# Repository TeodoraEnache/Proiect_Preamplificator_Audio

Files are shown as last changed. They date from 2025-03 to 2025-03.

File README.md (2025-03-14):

# 🔊Audio Preamplifier with Voltage-Controlled Gain – Design and Implementation

## Academic Context
### National University of Science and Technology POLITEHNICA Bucharest  
#### Faculty of Electronics, Telecommunications, and Information Technology  
##### Academic Year 2024-2025 
**Supervisors:**  
- Prof. Dr. Eng. Dragoș Dobrescu  
- Lecturer Dr. Eng. Mădălin Moise  

##  Table of Contents  

1. [ Description](#-description)  
2. [ Download Project](#download-project)  
3. [ Project Overview](#project-overview)  
4. [ Circuit Simulation and Testing](#-circuit-simulation-and-testing)  
   - [ Schematic](#schematic)  
   - [ SPICE Simulation](#spice-simulation)  
     - [First Simulation - Control voltage = 4V](#first-simulation---control-voltage4v)  
     - [Second Simulation - Control voltage = 0V](#second-simulation---control-voltage0v)  
5. [PCB Design](#pcb-design)  
   - [ PCB Layout](#pcb-layout)  
6. [Audio Preamplifier - PCB Layers](#audio-preamplifier---pcb-layers)  
   - [🔷 TOP Layer](#-top-layer)  
   - [🔷 BOTTOM Layer](#-bottom-layer)  
   - [🔷 SMTOP Layer (Solder Mask Top)](#-smtop-layer-solder-mask-top)  
   - [🔷 SMBOT Layer (Solder Mask Bottom)](#-smbot-layer-solder-mask-bottom)  
   - [🔷 SSTOP Layer (Silkscreen Top)](#-sstop-layer-silkscreen-top)  
   - [🔷 Outline Layer (Board Outline)](#-outline-layer-board-outline)  
   - [🔷 Fabrication Layer](#-fabrication-layer) 
7. [Repository Contents](#repository-contents)
8. [Conclusion](#conclusion)
9. [References](#references)

## Project Description: 

 A comprehensive project focused on designing and implementing an audio preamplifier with voltage-controlled gain, adjustable between 1x and 40x. The project includes:  
 • Designing the electrical schematic and simulating functionality using Cadence/Orcad PSpice.  
 • Creating a production-optimized SMD-based PCB layout.  
 • Providing detailed documentation, including theoretical analysis, applications, and manufacturing guidelines.

## Download Project:
[Click here to download the Project as PDF](https://github.com/TeodoraEnache/Proiect_Preamplificator_Audio/blob/main/Enache_Teodora_Preamplificator%20Audio.pdf)

## Project Overview

 The preamplifier is a crucial component of audio signal processing, enhancing low-level signals from sources such as microphones or pickups to levels that are suitable for further processing or amplification.The design's key feature is its voltage-controlled gain, which allows for precise adjustments to the amplification factor.  
 Adaptability is essential for ensuring audio fidelity in different input signal levels.

 ## Circuit Simulation and Testing

 ### Schematic
 
 The circuit schematic consists of a Darlington amplifier stage, which provides high current gain and high input impedance, making it suitable for low-power signal amplification. The circuit operates with a single positive power supply, using a common ground reference. After amplification and filtering, the processed audio signal is directed to the output stage, ensuring high-quality signal transmission.
 <br/>
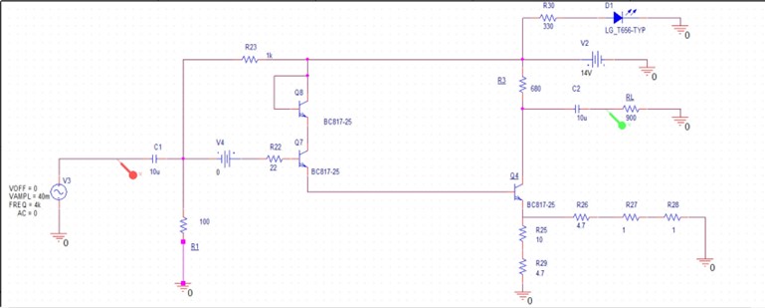
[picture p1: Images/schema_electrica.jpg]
Circuit

 <br/>  

 ### SPICE simulation 

 The result of the SPICE simulation demonstrate how the gain varies with the control voltage.

 #### First Simulation - Control voltage=4V
 The gain is low, when the control voltage is 4V. The output signal(GREEN) is weak, having almost the same amplitude as the imput signal (RED), indicating that the circuit functions as a signal repeater.
 <br/>
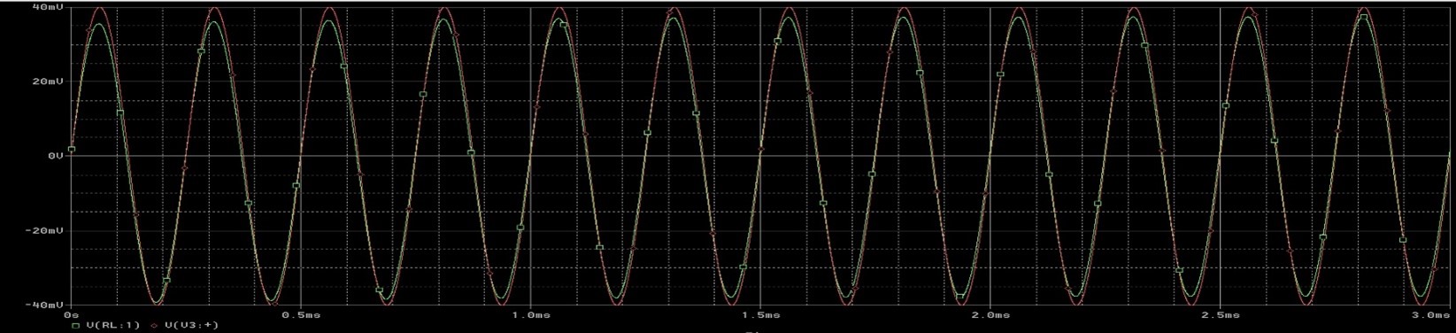
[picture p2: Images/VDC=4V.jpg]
Sim1

<br/>

#### Second Simulation - Control voltage=0V
The gain increases, when the control voltage is 0V. The output signal(GREEN) is amplified significantly, with the output amplitude increased by a factor of 40.
<br/>
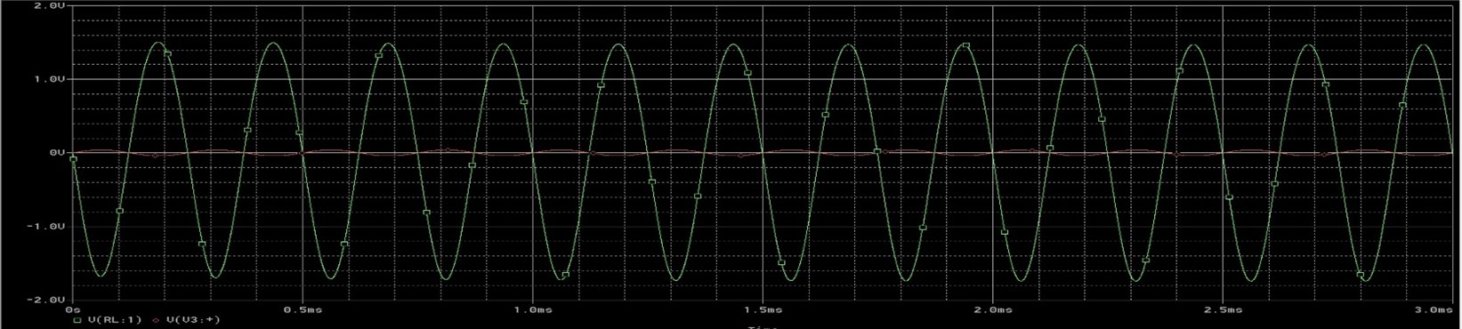
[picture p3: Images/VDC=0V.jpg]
Sim2

<br/>

 ### PCB DESIGN
 A custom PCB was designed for the practical implementation of this circuit. The layout optimizes component placement and signal routing to reduce noise and interference, ensuring a clean, amplified output. Measuring 40mm × 40mm, the compact PCB includes dedicated pads for input, output, power connections, and the control voltage signal, making it easily integrable into various audio applications.

 #### **Layout**

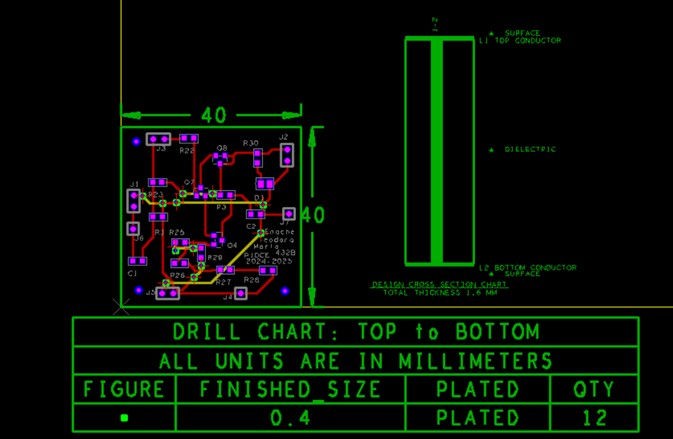
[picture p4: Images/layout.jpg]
PCB


### Audio Preamplifier - PCB Layers
#### 🔷 **TOP Layer** 
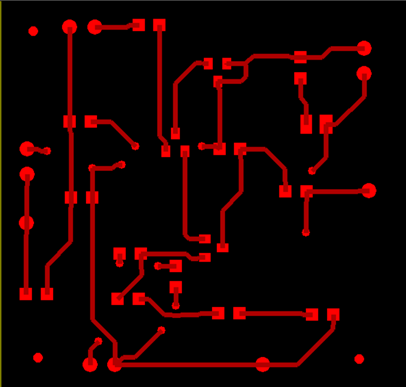
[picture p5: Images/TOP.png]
TOP

- Contains **all electronic components**, as per project requirements.
- Signal, power, and interconnection traces.
- Fiducial markers for precise alignment in the SMT assembly process.
#### 🔷 **BOTTOM Layer**
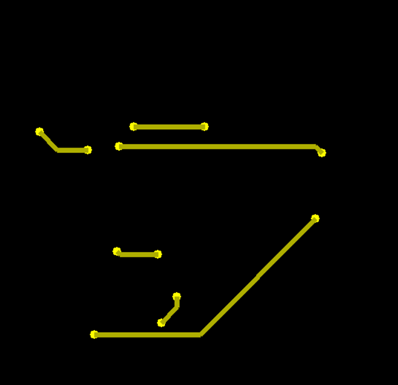
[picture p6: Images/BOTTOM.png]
BOTTOM

- Used for additional traces and interconnection through **vias (0.4mm diameter)**.
- Helps optimize circuit routing.
#### 🔷 **SMTOP Layer** *(Solder Mask Top)*
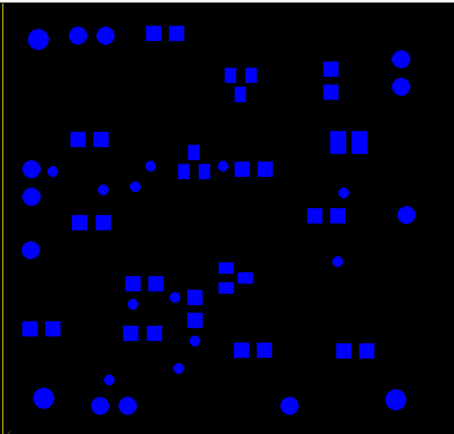
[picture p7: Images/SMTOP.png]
SMTOP

- A protective layer that covers exposed copper traces, preventing oxidation and short circuits.
- Only exposes the necessary soldering pads.

#### 🔷 **SMBOT Layer** *(Solder Mask Bottom)*
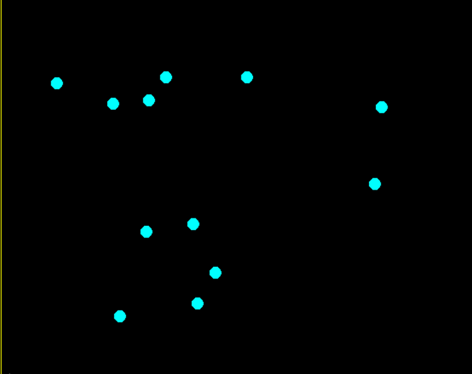
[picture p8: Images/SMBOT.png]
SMBOT

- Similar to SMTOP but applied to the bottom side of the board.
- Protects traces on the BOTTOM layer.

#### 🔷 **SSTOP Layer** *(Silkscreen Top)*
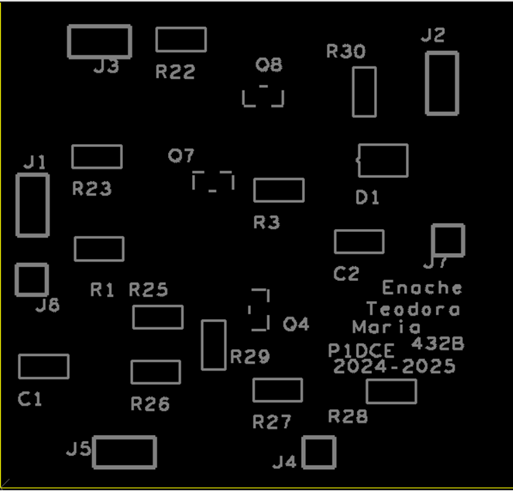
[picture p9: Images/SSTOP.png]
SSTOP

- A labeling layer containing component markings and assembly references.
- Must not overlap soldering pads.

#### 🔷 **Outline Layer** *(Board Outline)*
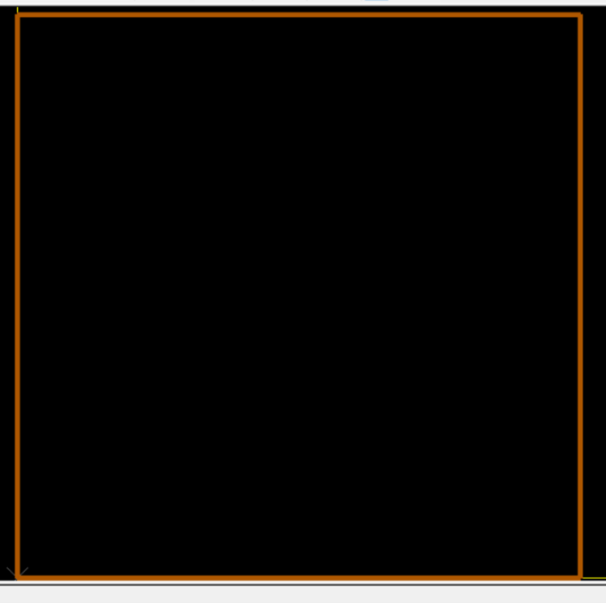
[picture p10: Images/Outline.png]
Outline

- Defines the PCB dimensions (**40mm x 40mm**).
- Includes the **(0,0) coordinate** origin mark in the bottom-left corner.
#### 🔷 **Fabrication Layer**
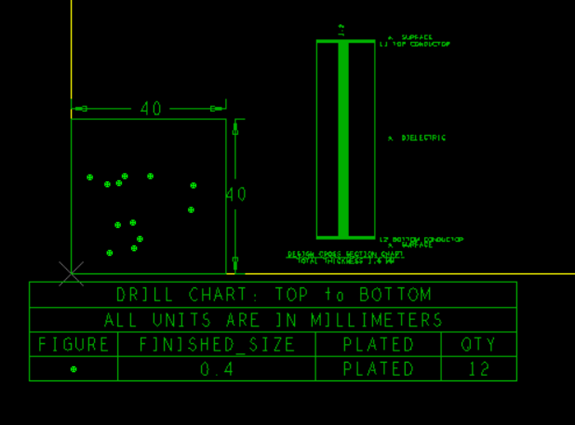
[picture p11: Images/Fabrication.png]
Fabrication

- Contains essential manufacturing information.

### Repository Contents
The repository includes essential design files:

-[Schematics](https://github.com/TeodoraEnache/Proiect_Preamplificator_Audio/tree/main/Schematic): Detailed circuit diagrams illustrating the preamplifier's design.

-[Layout](https://github.com/TeodoraEnache/Proiect_Preamplificator_Audio/tree/main/Layout): PCB layout designs for the physical implementation of the circuit.

-[Gerber and Excellon Files](https://github.com/TeodoraEnache/Proiect_Preamplificator_Audio/tree/main/Gerber_Excellon): Manufacturing files necessary for PCB fabrication.

-The project and its official documentation are available as a PDF.
 
 ### Conclusion 
 *This audio preamplifier project not only demonstrates the integration of theoretical and practical knowledge in audio electronics but also highlights the importance of a well-optimized PCB design. The carefully structured PCB layout ensures minimal noise, efficient signal routing, and proper thermal management, crucial for maintaining high-fidelity audio performance. By implementing a voltage-controlled gain feature and utilizing a compact, production-ready SMD layout, this design provides a scalable and reliable solution for various audio amplification needs.*

 ### References 
 1. Brezeanu,Gheorghe. Draghici, Florin. **Circuite Electronice fundamentale**, Ed. Niculescu (2013)
 2. Codreanu, Norocel. **Platforme Laborator Tehnici CAD de Realizare a Modulelor Electronice** (n.d.)
 3. Mitzner, K. **Complete PCB design using OrCAD Capture and PCB editor**, Newnes, 2009
 4. Popa, Cosmin Radu. **Platforma laborator** CIA (n.d.)

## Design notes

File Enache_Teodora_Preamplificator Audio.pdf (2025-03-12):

UNIVERSITATEA „POLITEHNICA” din BUCUREȘTI Facultatea de Electronică, Telecomunicații și Tehnologia Informației
Anul universitar 2024-2025

### Proiect 1

## Proiectarea și realizarea unui

## preamplificator audio cu amplificarea

## controlată de tensiune

N = 4

Coordonator științific:

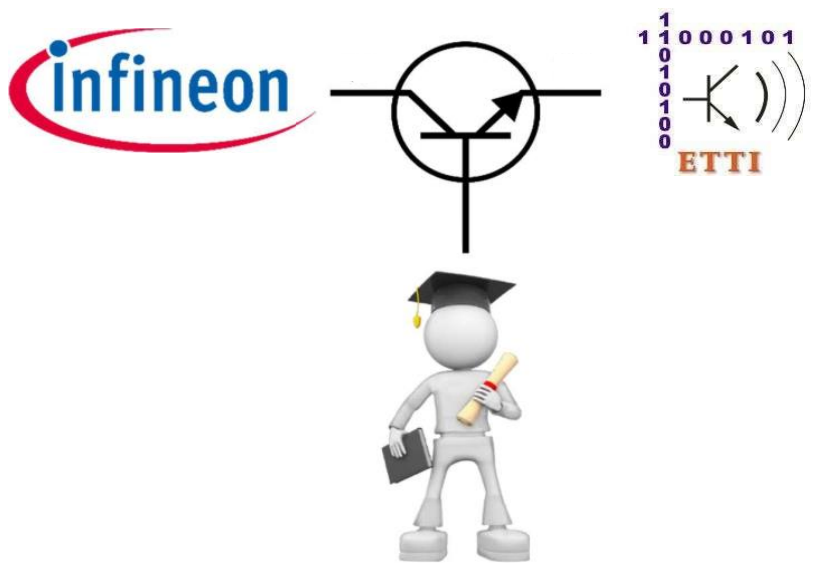
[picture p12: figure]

Prof. dr. ing. Dragoș Dobrescu Prof. dr. ing . Vasile Mădălin Moise

Enache Teodora-Maria
grupa 432B

## Cuprins

b. Simularile amplificatorului la valorile minima si maxima a tensiunii de control .....5

### I. Date inițiale de proiectare

a. Descrierea temei

Să se proiecteze şi să se realizeze practic un preamplificator de audiofrecvență cu control în tensiune având următoarele caracteristici:
- Tensiunea de alimentare unipolară (VCC=14 V) sau bipolară
(VCC=14V,
VEE= -VCC). Semnalizarea prezenței tensiunii cu LED.
- Tensiune de intrare sinusoidală cu amplitudinea cuprinsă între 0 și 40 mV.
- Frecvența semnalului de intrare de 4 kHz.
- Tensiunea continuă de control a amplificării cuprinsă între 0 și 4 V.
- Amplificarea în tensiune controlată cuprinsă între 1 și 40.
- Rezistența de sarcină 900 Ω.
b. Schema bloc a montajului electric

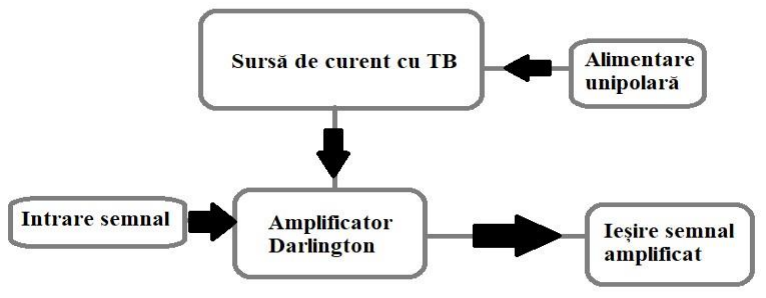
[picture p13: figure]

În schema de mai sus se disting următoarele blocuri:

- Intrare semnal: Introducerea inițială a semnalului audio, de obicei slab și necesitând amplificare.

- Amplificator: Amplificatorul Darlington reprezintă un etaj fundamental în proiectarea preamplificatoarelor audio, oferind un câștig mare de curent și o impedanță de intrare ridicată. Configurația constă în conectarea emitorului tranzistorului Q7 la baza tranzistorului Q4, ceea ce permite obținerea unui câștig de curent ridicat. Astfel, acest tip de amplificator este ideal pentru amplificarea semnalelor de mică putere, provenite de la surse precum microfoane sau instrumente muzicale. În schema prezentată, etajul de amplificare este completat de componente pasive care asigură stabilitatea și performanța optimă a circuitului, minimizând distorsiunile și zgomotul. Datorită acestei configurații, amplificatorul Darlington poate furniza o amplificare eficientă, menținând în același timp calitatea audio.
- Sursa de curent

Blocul compus din tranzistorul Q8, care acționează ca sursă de curent activă, furnizând un curent constant la colectorul tranzistorului Q7, joacă un rol crucial în menținerea stabilității, liniarității și performanței circuitului. Acesta contribuie esențial la obținerea unei amplificări precise a semnalului audio.

- Alimentare unipolară: Circuitul este alimentat de o singură sursă de tensiune pozitivă, având un punct de referință comun (masa).
- Ieșire: După procesul de amplificare și filtrare, semnalul audio este direcționat către blocul de ieșire.

4

### II. Detaliile tehnice ale proiectului

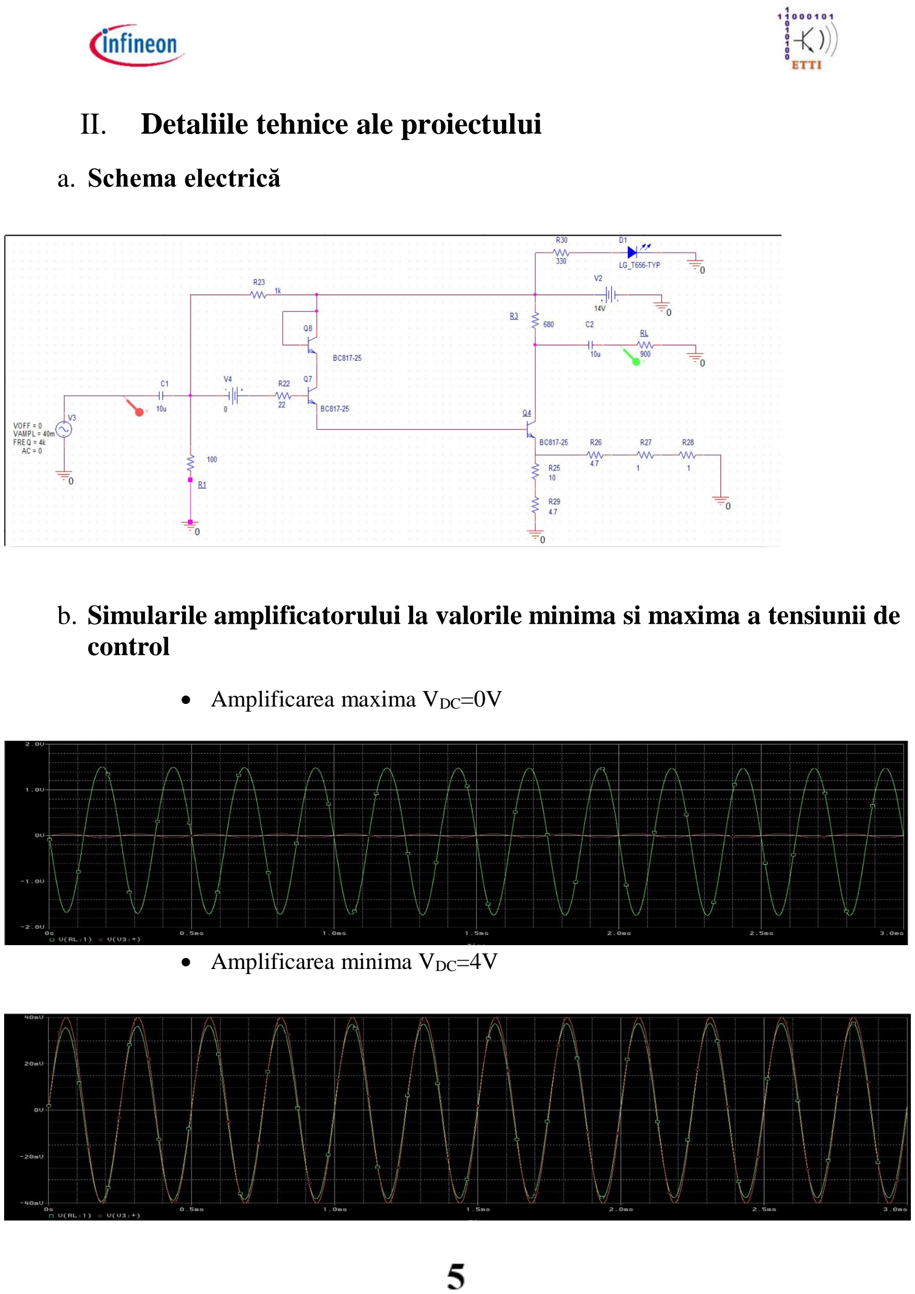
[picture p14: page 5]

a. Schema electrică
b. Simularile amplificatorului la valorile minima si maxima a tensiunii de control
- Amplificarea maxima VDC=0V
- Amplificarea minima VDC=4V

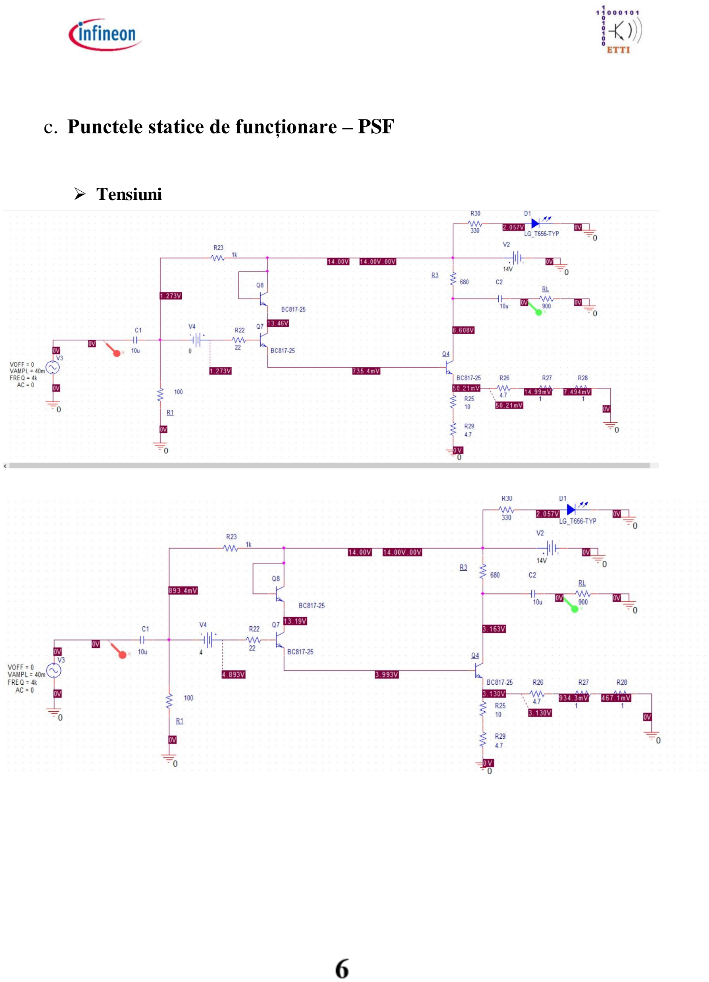
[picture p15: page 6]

c. Punctele statice de funcționare – PSF
- Tensiuni

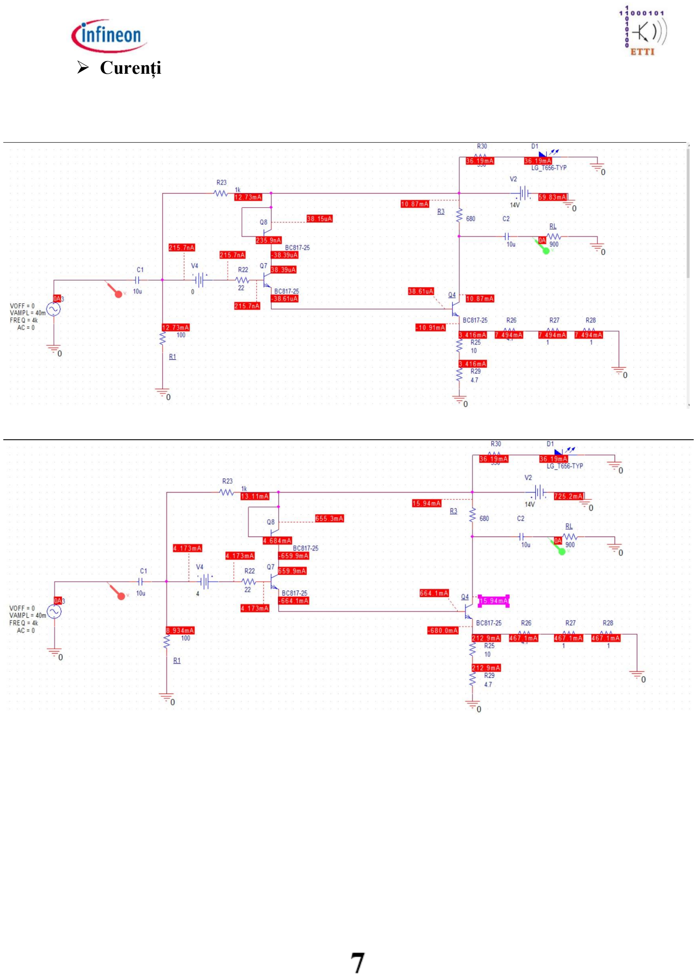
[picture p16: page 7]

- Curenți

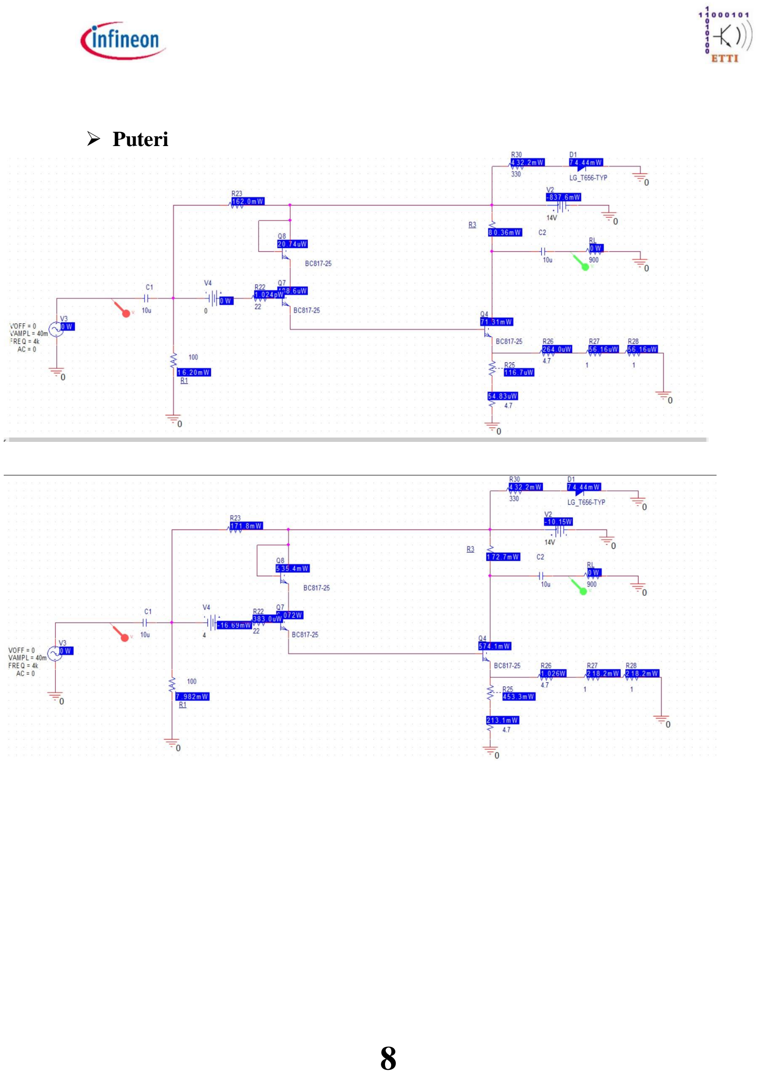
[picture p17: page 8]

- Puteri

8

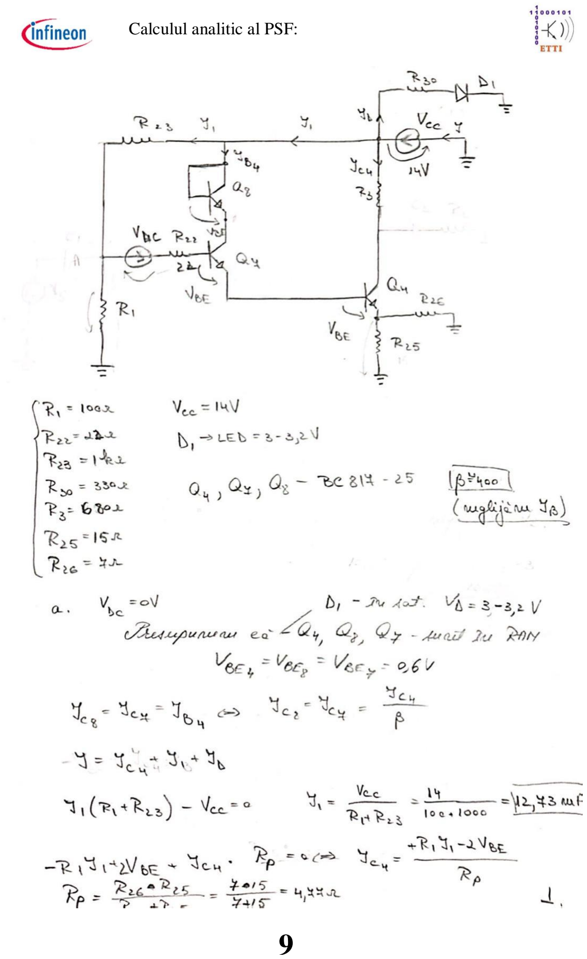
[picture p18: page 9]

9

Calculul analitic al PSF:

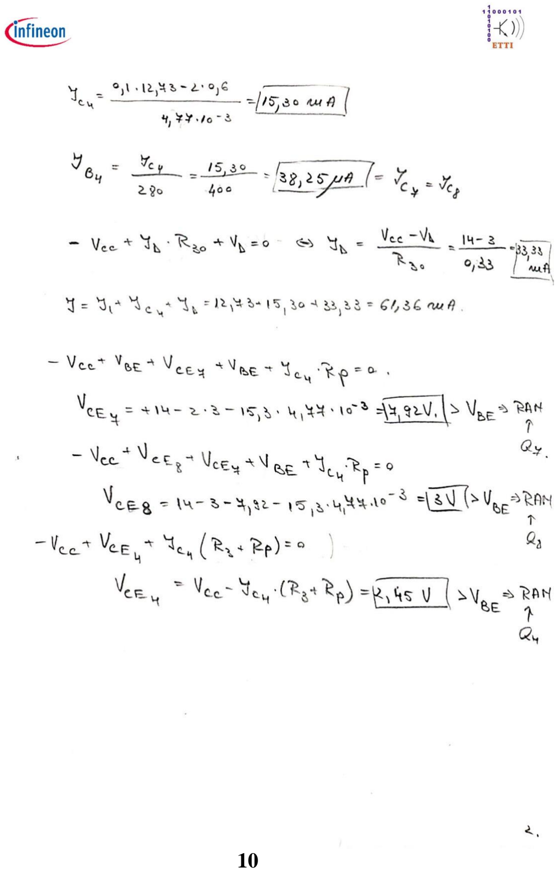
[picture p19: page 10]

10 d. Bill of Materials – BOM

Nume Referinta | Nume | Catalog | Cod distrib | Nume prod | Prod | Clasă | Descriere | Distribuitor
R27,R28 | 1 | (LINK) (https://www.tme.eu/ro/details/smd0805-1r/rezistente-smd-0805/royal-ohm/0805s8j010jt5e/) | SMD0805-1R-5% | 0805S8J010JT5E | ROYAL OHM | rezistor | Rezistor SMD, chip, 0805, 1Ω, ±5%, 0.125W | TME România
R26, R29 | 4.7 | (LINK) (https://www.tme.eu/ro/details/smd0805-4r7/rezistente-smd-0805/royal-ohm/0805s8j047jt5e/) | SMD0805-4R7-5% | 0805S8J047JT5E | ROYAL OHM | rezistor | Rezistor SMD, chip, 0805, 4.7Ω, ±5%, 0.125W | TME România
R25 | 10 | (LINK) (https://www.tme.eu/ro/details/smd0805-10r/rezistente-smd-0805/royal-ohm/0805s8j0100t5e/) | SMD0805-10R-5% | 0805S8J0100T5E | ROYAL OHM | rezistor | Rezistor SMD, chip, 0805, 10Ω, ±5%, 0.125W | TME România
R22 | 22 | (LINK) (https://www.tme.eu/ro/details/smd0805-22r-1%25/rezistente-smd-0805/royal-ohm/0805s8f220jt5e/) | SMD0805-22R-1% | 0805S8F220JT5E | ROYAL OHM | rezistor | Rezistor SMD, chip, 0805, 22Ω, ±1%, 0.125W | TME România
R1 | 100 | (LINK) (https://www.tme.eu/ro/details/smd0805-100r/rezistente-smd-0805/royal-ohm/0805s8j0101t5e/) | SMD0805-100R-5% | 0805S8J0101T5E | ROYAL OHM | rezistor | Rezistor SMD, chip, 0805, 100Ω, ±5%, 0.125W | TME România
R30 | 330 | (LINK) (https://www.tme.eu/ro/details/smd0805-330r/rezistente-smd-0805/royal-ohm/0805s8j0331t5e/) | SMD0805-330R-5% | 0805S8J0331T5E | ROYAL OHM | rezistor | Rezistor SMD, chip, 0805, 330Ω, ±5%, 0.125W | TME România
R3 | 680 | (LINK) (https://www.tme.eu/ro/details/smd0805-680r/rezistente-smd-0805/royal-ohm/0805s8j0681t5e/) | SMD0805-680R-5% | 0805S8J0681T5E | ROYAL OHM | rezistor | Rezistor SMD, chip, 0805, 680Ω, ±5%, 0.125W | TME România
R23 | 1k | (LINK) (https://www.tme.eu/ro/details/smd0805-1k/rezistente-smd-0805/royal-ohm/0805s8j0102t5e/) | SMD0805-1K-5% | 0805S8J0102T5E | ROYAL OHM | rezistor | Rezistor SMD, chip, 0805, 1kΩ, ±5%, | TME România
11

| | | | | | | 0.125W
C1, C2 | 10uF | (LINK) (https://www.tme.eu/ro/details/eee1ha100sp/condensatoare-electrolitice-smd/panasonic/) | EEE1HA100S P | EEE1HA100SP | PANASONIC | condensator | Condensa tor: electrolitic; SMD; 10uF; 50V | TME România
D2 | LED | (LINK) (https://www.tme.eu/ro/details/of-smd2012b/diode-led-smd-colorate/optoflash/) | OF-SMD2012B | OF-SMD2012B | OPTOFLASH | LED | LED albastru, SMD, 0805, 150-200mcd, 476nm, 120° | TME România
Q4, Q7, Q8 | NPN | (LINK) (http://www.tme.eu/ro/details/bc817-25-dio/tranzistori-smd-npn/diotec-semiconductor/bc817-25/) | BC817-25-DIO | BC817-25-DIO | NXP | tranzistor bipolar | Tranzistor bipolar NPN, SMD, SOT23, 45V, 800mA | TME România
J1, J2, J3, J5, | Conn2 p | (LINK) (http://www.tme.eu/ro/details/zl301-40p/pini-cu-benzi-si-soclu/ninigi/) | ZL301-40P | ZL301-40P | NINIGI | Sir pini, pas 2,54mm, SMD | Sir pini, pas 2,54mm, SMD, tip tata, bareta de 40 pini | TME România
J4, J6, J7 | Conn1 p | (LINK) (http://www.tme.eu/ro/details/zl301-40p/pini-cu-benzi-si-soclu/ninigi/) | ZL301-40P | ZL301-40P | NINIGI | Sir pini, pas 2,54mm, SMD | Sir pini, pas 2,54mm, SMD, tip tata, bareta de 40 pini | TME România

12

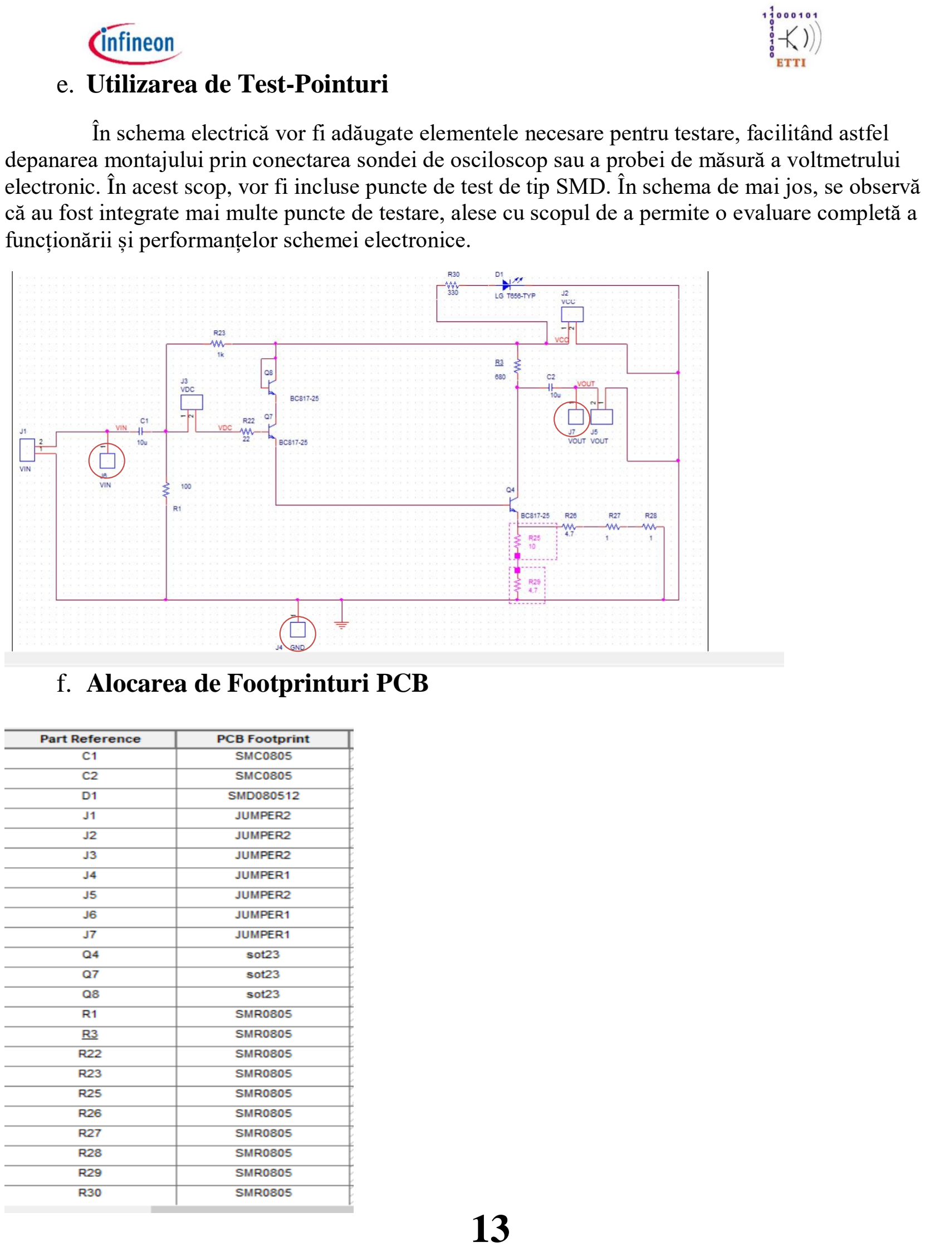
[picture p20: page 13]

e. Utilizarea de Test-Pointuri

În schema electrică vor fi adăugate elementele necesare pentru testare, facilitând astfel depanarea montajului prin conectarea sondei de osciloscop sau a probei de măsură a voltmetrului electronic. În acest scop, vor fi incluse puncte de test de tip SMD. În schema de mai jos, se observă că au fost integrate mai multe puncte de testare, alese cu scopul de a permite o evaluare completă a funcționării și performanțelor schemei electronice.

f. Alocarea de Footprinturi PCB

13

### III. Proiectarea și realizarea circuitului în tehnologie SMT & PCB

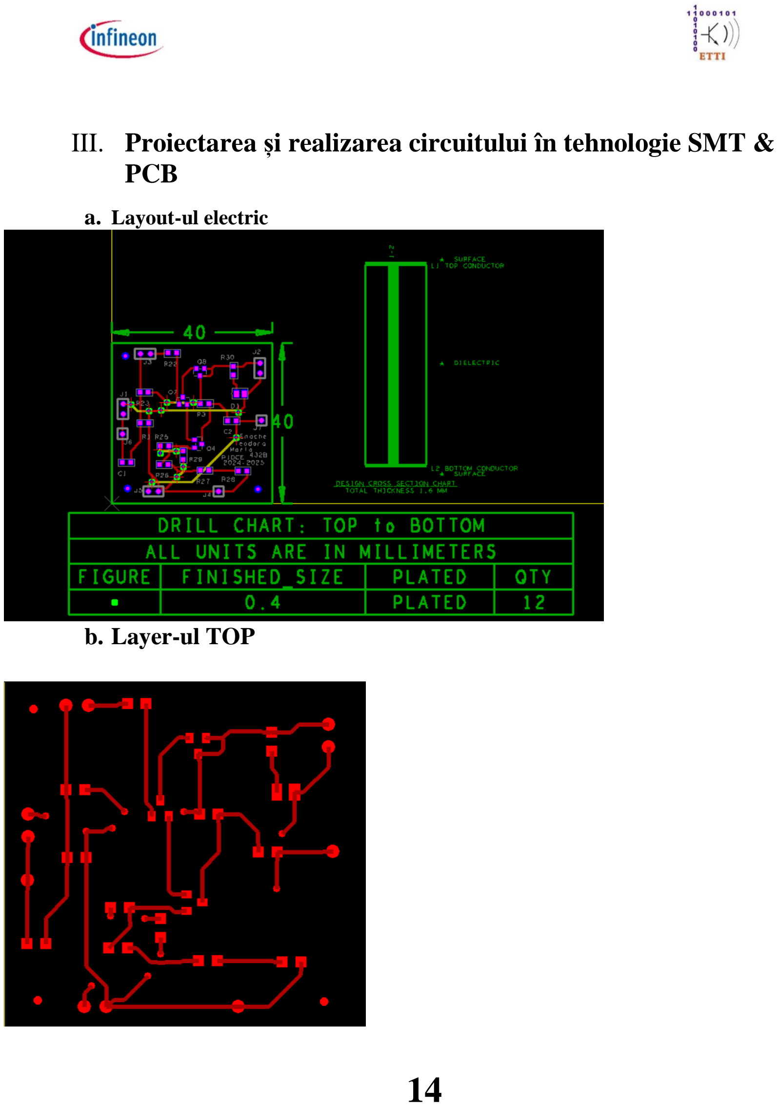
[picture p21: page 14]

a. Layout-ul electric
b. Layer-ul TOP

14

c. Layer-ul BOTTOM

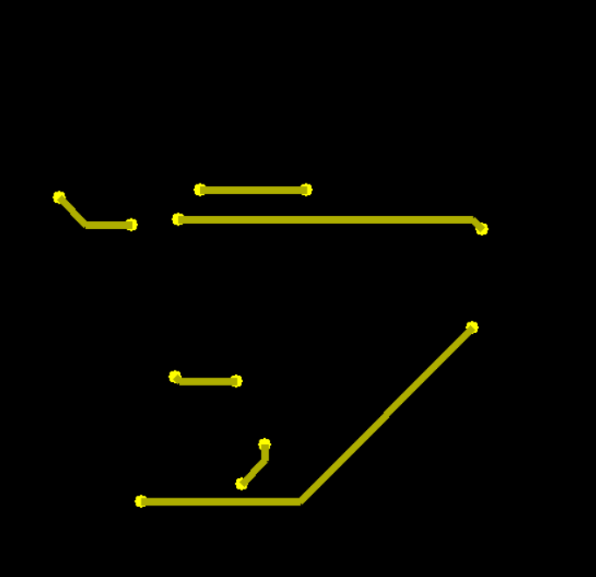
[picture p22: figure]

d. Layer-ul SMTOP

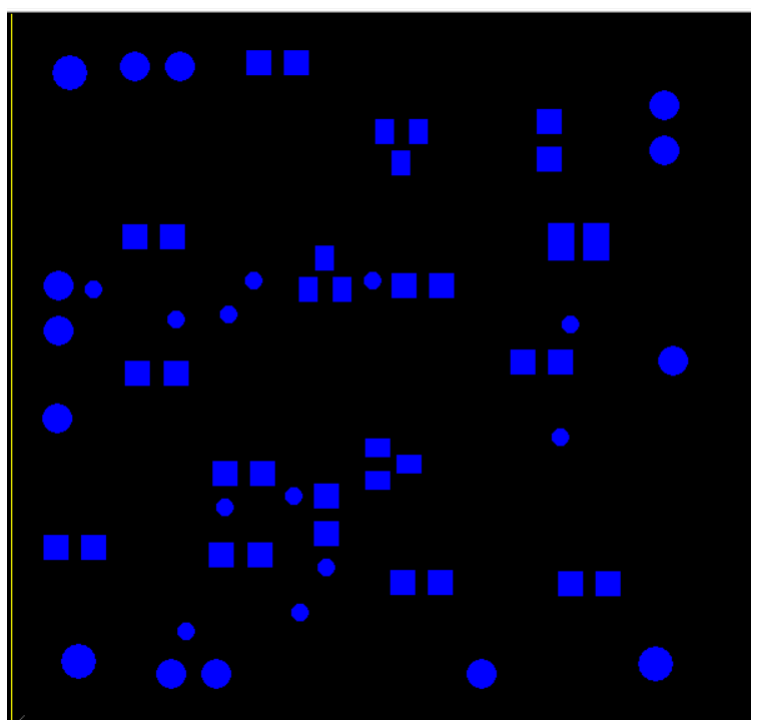
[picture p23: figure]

15

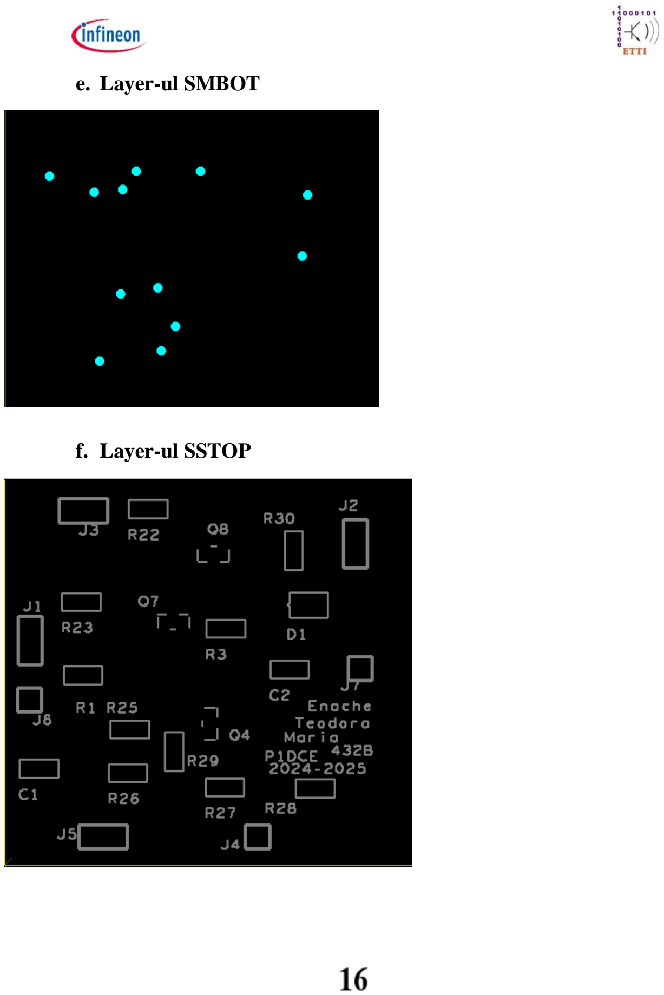
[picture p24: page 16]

e. Layer-ul SMBOT
f. Layer-ul SSTOP

g. Layer-ul Outline

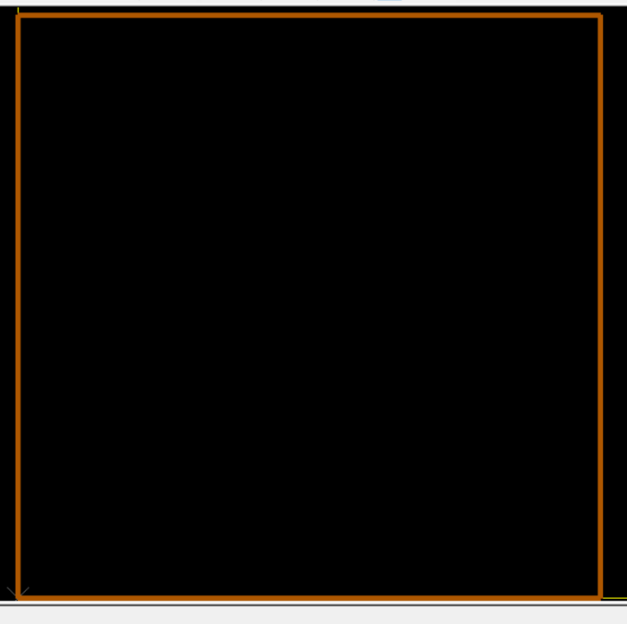
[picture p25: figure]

h. Layer-ul Fabrication

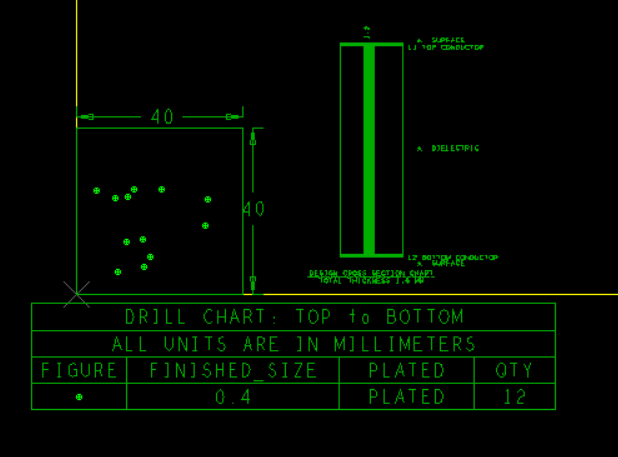
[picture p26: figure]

z

i. Mod de realizare

Unelte necesare

Lipirea componentelor electronice presupune fixarea și conectarea electrică a terminalelor acestora utilizând un aliaj de lipire, de obicei de tip SnAgCu. Pentru realizarea acestui proces sunt necesare următoarele unelte și materiale:

- Stația de lipit: permite controlul precis al temperaturii pentru a asigura o lipire corectă fără a deteriora componentele.
- Aliajul de lipire (cositor): majoritatea aliajelor moderne includ unul sau mai multe nuclee de flux în interiorul firului, care facilitează procesul de lipire prin reducerea tensiunii superficiale și îndepărtarea oxizilor.
- Flux suplimentar: agent chimic utilizat pentru curățarea suprafețelor de oxizi și impurități, îmbunătățind aderența aliajului.

Procedura de lipire

Temperatura vârfului de lipit se reglează la aproximativ 370°C pentru lipirea corectă a componentelor. La final, vârful stației de lipit nu trebuie curățat complet de cositor pentru a preveni oxidarea. Pentru corectarea lipiturilor, tresa absorbantă se așază între zona de cupru și vârful de lipit. Aliajul topit este transferat pe tresă odată ce aceasta atinge temperatura de topire. Este esențial ca tresa să fie utilizată perpendicular pe zona de curățare pentru a preveni deteriorarea padurilor de pe substrat. O stație de lipit bine întreținută și o tehnică precisă asigură o performanță optimă.

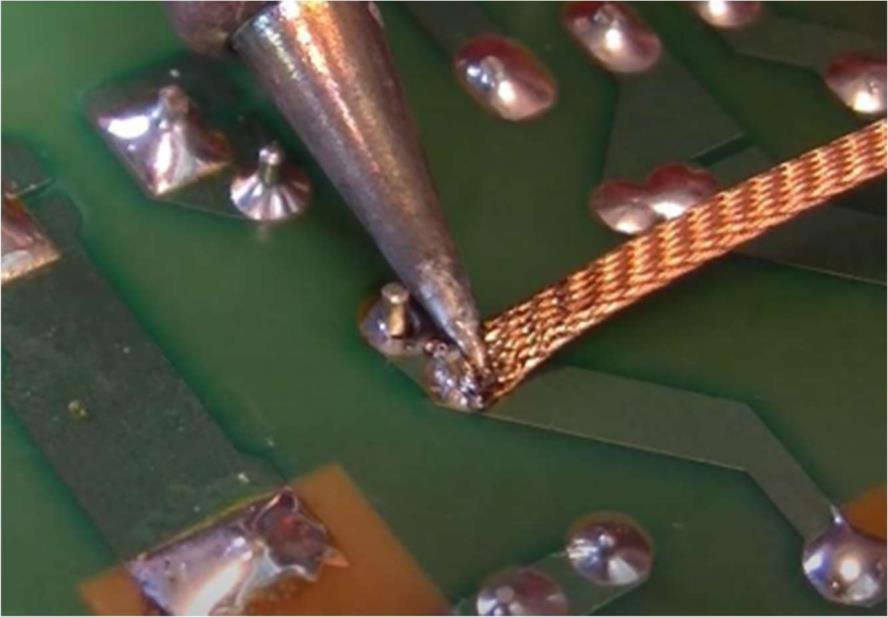
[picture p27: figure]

j. Manual de utilizare

Preamplificatorul a fost proiectat pentru a funcționa optim si de a avea o amplificare de tensiune cuprins intre 1 si 40 .

- Se vor conecta bornele – la borna GND;
- Tensiunea de intrare se va conecta la borna V1 (borna +);
- Tensiunea de alimentare pozitivă se va conecta la borna VCC, iar borna VSS (borna-) va fi conectată la masă (GND).
- Tensiunea de control se va conecta la borna VDC (borna +);
- A nu se atinge componentele sau conexiunile in timpul funcționarii;
- A se manevra ținandu-se de marginile placii de asamblare;
- Nu se recomandă schimbarea componentelor circuitului, în acest caz,
- Comportamentul nu poate fi determinat;
- A se feri de umezeală și expunerea îndelungată la razele soarelui;

### IV. Concluzie

Proiectul de față a implementat cu succes un preamplificator audio cu amplificare controlată de tensiune, respectând cerințele specificate în documentația inițială. Aparatul oferă caracteristici tehnice de înaltă precizie, incluzând amplificare ajustabilă între 1 și 40, compatibilitate cu alimentare unipolară sau bipolară și semnalizare LED pentru indicarea tensiunii de alimentare. Viabilitatea designului a fost demonstrată prin schema electrică, simulările realizate și implementarea PCB, iar documentația detaliată acoperă toate aspectele proiectării, materialelor și utilizării practice. Proiectul îmbină în mod util aplicarea cunoștințelor teoretice în soluții practice ale ingineriei electronice.

20

### V. Bibliografie

- ”Circuite Electronice fundamentale”- Gheorghe Brezeanu, Florin Draghici
- Platforme Laborator Tehnici CAD de Realizare a Modulelor Electronice, Norocel Codreanu
- Note de curs - Circuite electronice fundamentale, Dragoș Dobrescu
- Platforma laborator CIA, Popa Cosmin Radu

21
